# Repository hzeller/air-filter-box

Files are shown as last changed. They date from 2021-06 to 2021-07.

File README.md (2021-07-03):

# Air filter box

Getting ready for the next wildfire season.

This is using [MERV13 filters from Amazon](https://amazon.com/dp/B00CJZ7TB2)
as well as the guts from
[some well-made fans](https://amazon.com/dp/B08GLV99T9).

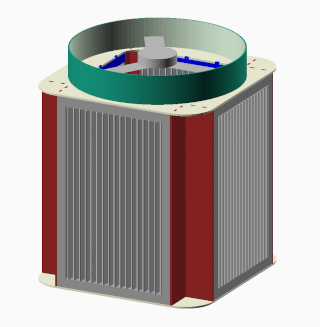
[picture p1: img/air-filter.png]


### Generate file

The cut is dependent on the thickness of the used plywood. To generate DXF
file, [OpenSCAD] needs to be installed. Then, measure the
actual thickness of the plywood with calipers.

Let's assume we measure **5.7mm**. Then this command will generate the necessary
DXF file:

```
make air-filter-cuts-5.7mm.dxf
```

As an example, there is a 5.5mm size pre-generated [air-filter-cuts-5.5mm.dxf](./air-filter-cuts-5.5mm.dxf) in this directory.

### Laser cut

Everything is in one big DXF file of which probably parts have to be disabled
to cut one at a time on a normal-sized laser cutter :)

To laser-cut, it is probably good to use an inward kerf correction for the
finger slots.

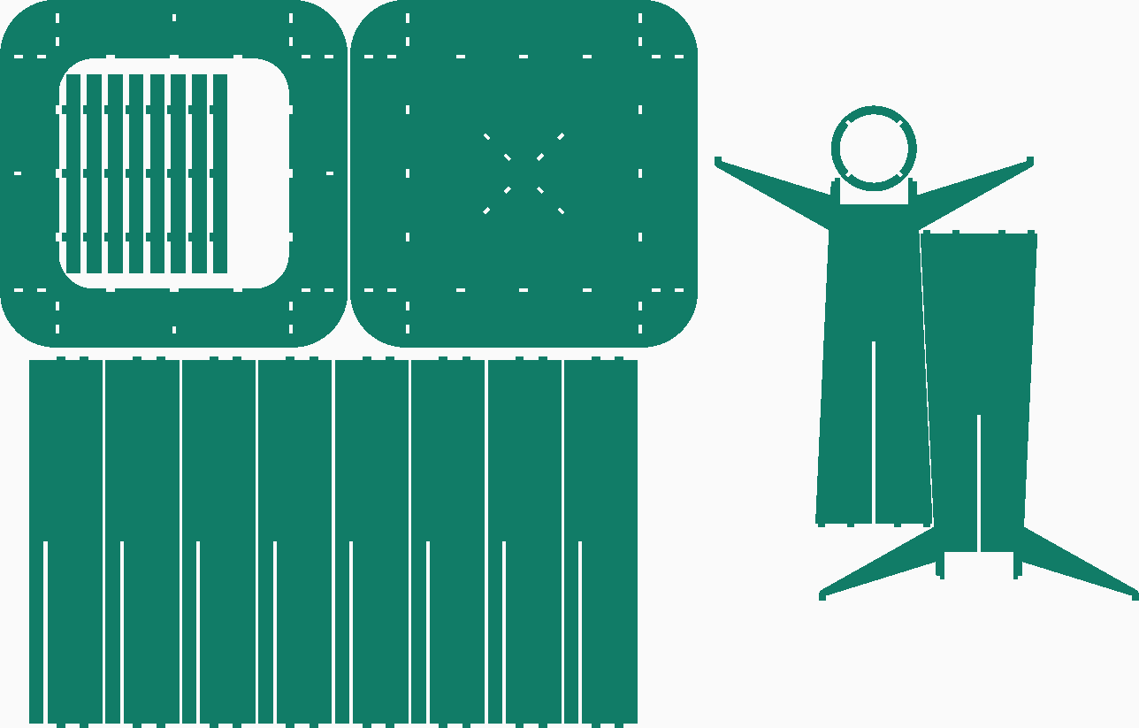
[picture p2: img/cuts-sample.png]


### Assembly

Glue in top and bottom filter stopper (shown in blue below first).

Corner parts have to be slotted together length-wise, then the bottom and
top finger joints fit exactly with the corresponding top and bottom plate.

Corner parts can be glued.



If things look like this, PM2.5 is probably high, and it is good to have
such filter:
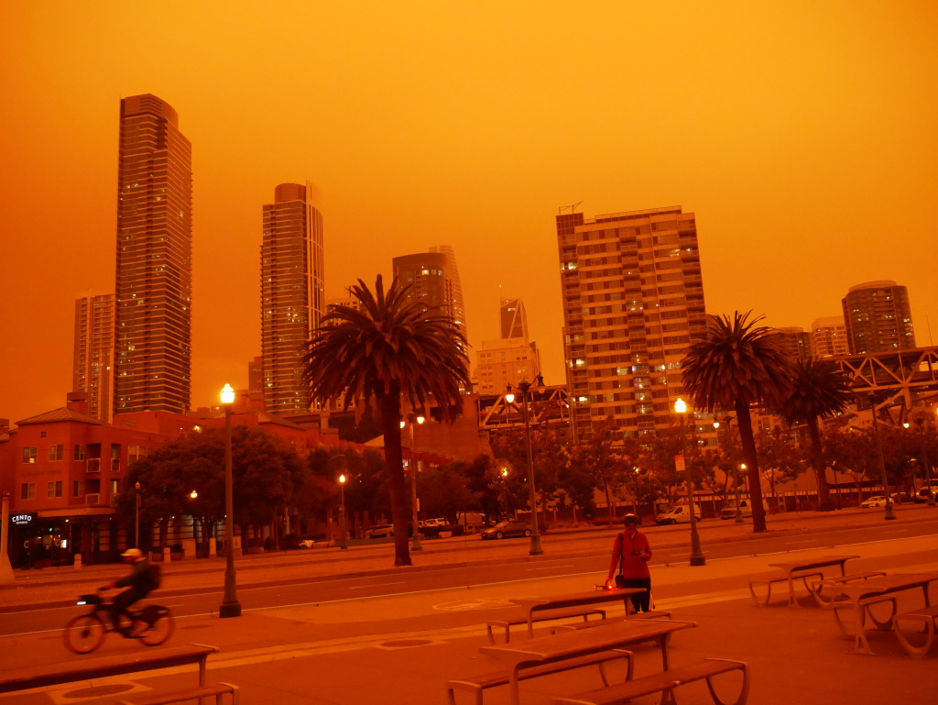
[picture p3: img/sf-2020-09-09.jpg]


[OpenScad]: https://openscad.org/downloads.html

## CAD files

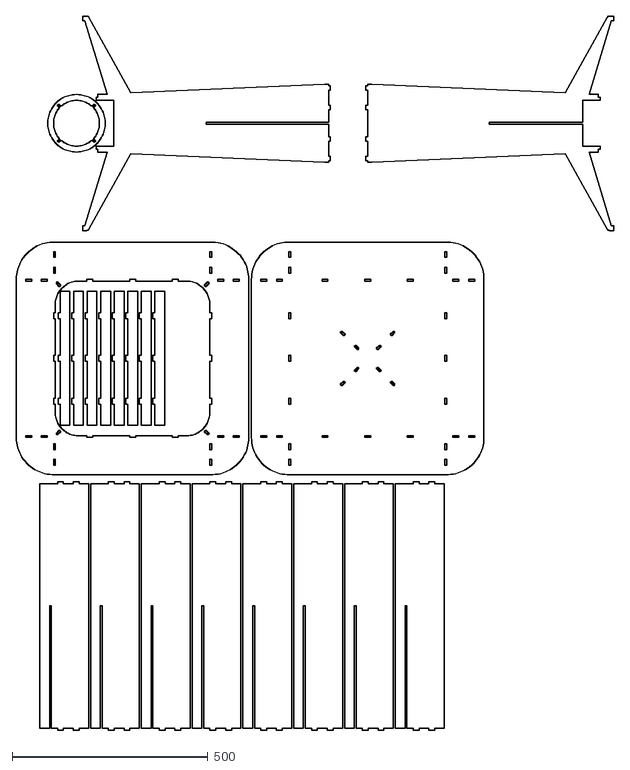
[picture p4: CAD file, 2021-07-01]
air-filter-cuts-4.6mm.dxf
1524.2 x 1821.8

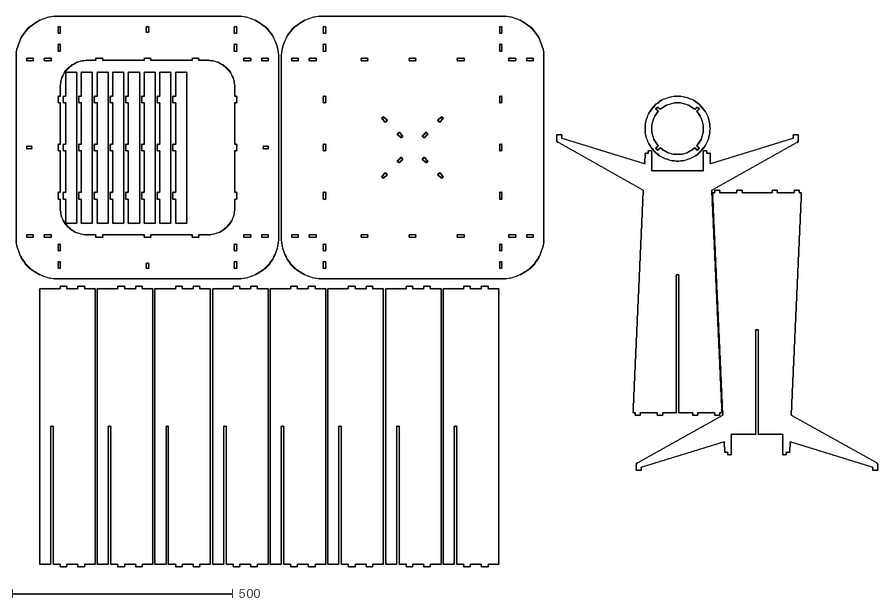
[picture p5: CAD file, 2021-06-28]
air-filter-cuts-5.5mm.dxf
1951.2 x 1246.4

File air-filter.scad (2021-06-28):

// (c) 2021 Henner Zeller. License: CC-BY-SA
$fn=90;
e=0.05;

ply_thick=6;      // mm. Measured plywood thickness.
ply_wiggle=0.1;   // Space around slots finger slots.

filter_wiggle_room=1;

// Filter sizes according to https://amazon.com/dp/B00CJZ7TB2
// (but then measured)
filter_w = (filter_wiggle_room + 393);   // mm Wide
filter_h = (filter_wiggle_room + 622);   // mm High
filter_t = (filter_wiggle_room + 94);    // mm Thick

filter_rim=25;             // cardboard edge around filter

fan_inner_r=10*25.4;       // Visualization of fan size.
fan_hold_ring_inner=117;
fan_hold_ring_outer=fan_hold_ring_inner + 2*15;
fan_foam_thick=30;

fan_ring_pos=filter_h - ply_thick - fan_foam_thick;

// Animation of the 'explosion' view.
explode_factor=-cos(360*$t)/2+0.5;

module filter_material(h=filter_h-filter_wiggle_room-2*filter_rim,
		       thick=filter_t, d=10,
		       w=filter_w-filter_wiggle_room-2*filter_rim) {
     r=3;
     color("lightgray") {
	  for (yoff = [-w/2 : 2*d : w/2]) translate([0, yoff, 0]) {
	       hull() {
		    cylinder(r=r, h=h);
		    translate([thick, d, 0]) cylinder(r=r, h=h);
	       }
	       hull() {
		    translate([thick, d, 0]) cylinder(r=r, h=h);
		    translate([0, 2*d, 0]) cylinder(r=r, h=h);
	       }
	  }
     }
}

module zarge(left=false, ply_thick = ply_thick, extra=0) {
     center_clearance=0.8;  // Leave a bit of center wiggle room
     outer_move = filter_rim + ply_thick;
     color("brown") translate([-outer_move, 0, 0]) {
	  difference() {
	       cube([filter_t + outer_move, ply_thick, filter_h]);
	       translate([filter_rim-ply_wiggle/2, -25,
			  left ? 0 : filter_h/2-center_clearance])
		    cube([ply_thick+ply_wiggle, 50, filter_h/2+center_clearance]);
	  }

	  // Fingers mounting to top/bottom.
	  finger_w=15;
	  for (notch = [0.2, 0.7]) {
	       translate([notch * (filter_t-finger_w) + outer_move - extra, -extra/2, -ply_thick-0.5]) cube([finger_w+2*extra, ply_thick+extra, filter_h+2*ply_thick+1]);
	  }
     }
}

module bottom_stop(extra=0) {
     w = filter_w - 2*filter_rim - 2;
     color("blue") translate([-ply_thick, -w/2, 0]) {
	  cube([ply_thick, w, filter_rim]);
	  finger_w=15;
	  for (notch = [1/6, 3/6, 5/6]) {
	       translate([-extra/2, notch * (w-finger_w) - extra, -ply_thick-0.5]) cube([ply_thick+extra, finger_w+2*extra, filter_rim+ply_thick+0.5]);
	  }
     }
}

module filter_zargen(extra=0, explode=0) {
     z_explode=1.1 * filter_h * explode;
     translate([0, -filter_w/2-ply_thick, z_explode]) zarge(left=true, extra=extra);
     translate([0, +filter_w/2, 0]) zarge(left=false, extra=extra);

     stop_explode = 0.2*filter_h*explode;
     translate([0, 0, stop_explode]) bottom_stop(extra=extra);
     translate([-ply_thick, 0, filter_h+1.2*filter_h*explode]) rotate([0, 180, 0]) bottom_stop(extra=extra);
}

module filter(show_filter=true, extra=0, explode=0) {
     // 15.38" x 24.38" x 3.63"
     if (show_filter) {
	  fw = filter_wiggle_room;
	  translate([0, 0, filter_rim+fw/2]) filter_material();
	  translate([0, -(filter_w-fw) / 2, fw/2])
	       if (true) color("darkgray") difference() {
			 cube([filter_t, filter_w-fw, filter_h-fw]);
			 translate([-e, filter_rim, filter_rim])
			      cube([filter_t+2*e, filter_w-fw-2*filter_rim, filter_h-fw-2*filter_rim]);
		    }
     }

     filter_zargen(extra=extra, explode=explode);
}

module filter_half_box(show_filter, extra=0, explode=0) {
     translate([filter_w/2 + ply_thick, 0, 0])
	  filter(show_filter, extra, explode);
     translate([0, filter_w/2+ply_thick, 0])
	  rotate([0, 0, 90]) filter(show_filter, extra, explode);
}

module filter_box(show_filter=true, extra=0, explode=0) {
     filter_half_box(show_filter, extra, explode);
     rotate([0, 0, 180]) filter_half_box(show_filter, extra, explode);
}

module fan_ring_base() {
     difference() {
	  cylinder(r=fan_hold_ring_outer/2, h=ply_thick);
	  translate([0, 0, -e]) cylinder(r=fan_hold_ring_inner/2, h=ply_thick+2*e);
     }
}

module fan_ring() {
     difference() {
	  fan_ring_base();
	  translate([0, 0, -fan_ring_pos]) {
	       rotate([0, 0, -45]) fan_holder();
	       rotate([0, 0, +45]) fan_holder();
	  }
     }
}

module fan_holder(extra=0, left=false) {
     center_clearance=0.8;  // Leave a bit of center wiggle room
     finger_w=12;
     t = ply_thick + extra;
     diagonal = (filter_w-7) * sqrt(2);
     center_w=fan_hold_ring_outer;
     difference() {
	  union() {
	       // Main body
	       hull() {
		    translate([-t/2, -center_w/2, 0]) cube([t, center_w, fan_ring_pos]);
		    translate([-t/2, -200/2, 0]) cube([t, 200, 10]);
	       }


	       // one side-arm
	       for (symmetry = [-1, 1]) hull() {
		    translate([-t/2, symmetry*(diagonal/2-finger_w/2), filter_h-e-finger_w/2])
			 rotate([0, 90, 0]) cylinder(r=finger_w/2, h=t);

		    translate([-t/2, symmetry*fan_hold_ring_inner/2, fan_ring_pos-60])
			 rotate([0, 90, 0]) cylinder(r=30, h=t);
	       }

	  }

	  // Space to house motor
	  translate([0, 0, fan_ring_pos - 40])
	       cylinder(r=fan_hold_ring_inner/2, h=45);

	  // Vertical slot
	  translate([-25, -t/2, left ? 0 : filter_h/2-center_clearance])
	       cube([50, t, filter_h/2+center_clearance]);
     }

     // vertical slot needed

     for (symmetry = [-1, 1]) {
	  scale([1, symmetry, 1]) {
	       // Bottom fingers
	       for (notch = [40, 90]) {
		    translate([-t/2, notch-finger_w/2, -ply_thick-e]) cube([t, finger_w, ply_thick+2*e]);
	       }

	       // Top fingers
	       translate([-t/2, diagonal/2-finger_w, filter_h-e-finger_w/2]) cube([t, finger_w, ply_thick+2*e+finger_w/2]);

	       // Fingers for motor fan_ring
	       translate([-t/2, fan_hold_ring_inner/2-2*e, fan_ring_pos]) cube([t, 8, ply_thick+2*e]);
	  }
     }
}

module fan() {
     if (false) difference() {  // inner shroud
	  cylinder(r=fan_inner_r, h=100);
	  translate([0, 0, -e]) cylinder(r=9.8 * 25.4, h=101);
     }
     if (true) difference() {  // outer shroud
	  cylinder(r=550/2, h=100);
	  translate([0, 0, -e]) cylinder(r=540/2, h=101);
     }
     d=60;
     translate([0, 0, 50]) color("silver") {
	  cylinder(r=d, h=30);
	  for (a = [0, 120, 240]) {
	       rotate([0, 0, a])
		    translate([0, -60/2, 0]) cube([19/2 * 25.4, 60, 0.1]);
	  }
     }
}

module rounded_box(w, h, r, thick=ply_thick) {
     hull() {
	  ww = w/2 - r;
	  hh = h/2 - r;
	  for (x = [-1, 1]) {
	       for (y = [-1, 1]) {
		    translate([x*ww, y*hh, 0]) cylinder(r=r, h=thick);
	       }
	  }
     }
}

module box_end() {
     d = filter_w + 2*(filter_t + ply_thick);
     color("beige") rounded_box(d, d, filter_t);
}

module bottom_board() {
     difference() {
	  translate([0, 0, -ply_thick]) box_end();
	  translate([0, 0, e]) filter_box(show_filter=false, extra=ply_wiggle);
	  rotate([0, 0, +45]) fan_holder(extra=ply_wiggle);
	  rotate([0, 0, -45]) fan_holder(extra=ply_wiggle);
     }
}

module top_board() {
     difference() {
	  translate([0, 0, filter_h]) difference() {
	       box_end();
	       d = filter_w + 0.5;
	       translate([0, 0, -e]) rounded_box(d, d, 60, ply_thick+1);
	  }
	  filter_box(show_filter=false, extra=ply_wiggle);

	  fan_holder(extra=ply_wiggle);
	  rotate([0, 0, 90]) fan_holder(extra=ply_wiggle);
     }
}


module assembly(show_filter=true) {
     translate([0, 0, -0.3*filter_h * explode_factor]) bottom_board();
     translate([0, 0, 1.3*filter_h * explode_factor]) top_board();
     filter_box(show_filter=show_filter, explode=explode_factor);
     translate([0, 0, filter_h + 1.5*filter_h * explode_factor]) fan();

     translate([0, 0, 1.1*filter_h * explode_factor])
	  rotate([0, 0, -45]) fan_holder(left=true);
     rotate([0, 0, +45]) fan_holder();
     translate([0, 0, 1.15*filter_h * explode_factor])
	  translate([0, 0, fan_ring_pos]) fan_ring();
}

module top_2d() { projection(cut=false) top_board(); }
module bottom_2d() { projection(cut=false) bottom_board(); }
module zarge_2d() {
     projection(cut=false) rotate([90, 0, 0]) zarge(extra=0);
}

module fan_ring_2d() {
     projection(cut=false) fan_ring();
}

module fan_holder_2d(left=true) {
     projection(cut=false) rotate([0, 90, 0]) fan_holder(extra=ply_wiggle, left=left);
}

module bottom_stop2d() {
     projection(cut=false) rotate([0, 90, 0]) bottom_stop();
}

module cuts() {
     translate([-300, 0, 0]) top_2d();
     translate([300, 0, 0]) bottom_2d();
     for (i = [0 : 7]) {
	  translate([400 - i*(filter_t+filter_rim+ply_thick+5), -320, 0]) zarge_2d();
     }

     // Place these inside the empty space of the top.
     translate ([-485, 0, 0]) {
	  for (i = [0 : 7]) {
	       translate([i * (ply_thick+filter_rim+5), 0, 0]) bottom_stop2d();
	  }
     }

     translate([900, -600, 0]) {
	  translate([0, filter_h+20, 0]) fan_ring_2d();
	  translate([180, filter_h-125, 0]) rotate([0, 0, -90]) fan_holder_2d(left=false);
	  rotate([0, 0, 90]) fan_holder_2d(left=true);
     }
}


//cuts();
rotate([0, 0, 180*$t]) assembly(show_filter=false);

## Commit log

2021-06-15 Initial commit air filter box.
    [air-filter.scad]
2021-06-15 Pre-generate a 5.5mm plywood thick file as example.
    [air-filter-cuts-5.5mm.dxf]
2021-06-15 Add image with filter shown.
2021-06-28 Use exactly measured size of filter.
    [air-filter.scad]
2021-06-28 Add a holder for the fan motor.
    [air-filter-cuts-5.5mm.dxf, air-filter.scad]
2021-06-28 Update TODO section about fan holder, now finished.
2021-07-01 Add a 4.7mm dxf
    [air-filter-cuts-4.6mm.dxf]
2021-07-01 Update 4.6mm dxf
    [air-filter-cuts-4.6mm.dxf]
2021-07-03 Add link to used fan.
